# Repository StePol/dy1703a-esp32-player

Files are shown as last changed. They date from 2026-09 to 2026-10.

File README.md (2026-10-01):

# DY1703A ESP32 Audio Player

Prehrávač zvukov založený na module **DY1703A / DY-SV17F** a riadený **ESP32 DevKit**. Projekt obsahuje firmvér, KiCad schému a lokálne KiCad knižnice.

> Dokumentácia zodpovedá aktuálnemu obsahu vetvy `main`.

## Funkcie

- prehrávanie až 8 skladieb,
- 8 fyzických tlačidiel,
- webové ovládanie cez Wi-Fi,
- STA alebo vlastný AP režim,
- Play / Pauza / Stop,
- hlasitosť 0–30 a uloženie štartovacej hlasitosti,
- názvy skladieb,
- pevné identifikátory skladieb 1–8,
- samostatný externý odkaz pre každú skladbu,
- samostatné PNG/JPG logo pre každú skladbu,
- individuálne vibrácie,
- individuálny LOOP,
- orientačné meranie batérie,
- hlavné logo PNG/JPG v LittleFS a externý odkaz z hlavného loga,
- prehľad využitia LittleFS vrátane priestoru obsadeného logami,
- heslom chránené nastavenia,
- záloha/obnova konfigurácie,
- výrobné nastavenia,
- automatická verzia + Git SHA + build number,
- pomocný `release.py` na automatické zvýšenie PATCH/MINOR/MAJOR verzie,
- light sleep,
- servisné Serial príkazy.

## Dôležitá poznámka k Bluetooth

V `platformio.ini` je deklarovaná závislosť NimBLE-Arduino, ale aktuálny `src/main.cpp` BLE rozhranie nepoužíva. Starší README uvádzal Bluetooth ako vlastnosť projektu; podľa aktuálneho zdrojového kódu ho preto nemožno považovať za hotovú funkciu.

## Webové rozhranie

Nastavenia sú rozdelené na:

1. **Logo**
2. **Zariadenie a Wi-Fi**
3. **Nastavenie skladieb**
4. **Údržba**

Predvolené heslo pre nastavenia je `12345`. Predvolené AP heslo je `password`. Web používa HTTP bez TLS, preto je pri nasadení vhodné predvolené heslá zmeniť.

## UART DY1703A

| Funkcia | ESP32 |
|---|---:|
| TX → DY RX | GPIO17 |
| RX ← DY TX | GPIO16 |
| Baudrate | 9600 |
| Formát | 8N1 |

Firmware používa rámce začínajúce `0xAA` a podporuje play, pause, stop, previous, next, play track, volume a play state.

## GPIO podľa aktuálneho firmvéru

| Funkcia | GPIO |
|---|---:|
| Motor | 4 |
| Track 1 | 25 |
| Track 2 | 33 |
| Track 3 | 32 |
| Track 4 | 35 |
| Track 5 | 13 |
| Track 6 | 14 |
| Track 7 | 27 |
| Track 8 | 26 |
| Battery ADC | 34 |
| Battery enable | 23 |
| UART RX | 16 |
| UART TX | 17 |

> `docs/wiring.md` obsahuje staršie poradie GPIO pre tlačidlá. Pred výrobou treba zosúladiť firmware, schému a skutočnú kabeláž.

## Batéria

Používa sa spínaný odporový delič:

- ADC GPIO34,
- enable GPIO23,
- R_TOP 100 kΩ,
- R_BOTTOM 100 kΩ.

Delič je mimo merania odpojený. Percentá sú lineárny orientačný odhad 3,0–4,2 V.

## KiCad

Projekt je v `docs/kicad/dy1703a/` a obsahuje:

- `dy1703a.kicad_pro`
- `dy1703a.kicad_sch`
- `dy1703a.kicad_pcb`
- `dy1703a.kicad_sym`
- `dy1703a.pretty/`
- `LX-LCBST/`
- `fp-lib-table`
- `sym-lib-table`

Schéma má titulný blok s názvom **Zapojenie Prehravaca s ESP32 A DY1703A**, dátumom 2026-09-16, revíziou 1.0 a autorom Stefan Polacik.

**PCB je zatiaľ prázdna základná PCB štruktúra; nejde ešte o výrobný návrh.**

## Štruktúra

```text
dy1703a-esp32-player/
├── include/
│   └── config.h
├── lib/
│   ├── DY1703A/
│   └── BatteryMonitor/
├── src/
│   └── main.cpp
├── docs/
│   ├── architecture.md
│   ├── hardware.md
│   ├── software.md
│   ├── kicad.md
│   ├── wiring.md
│   └── kicad/dy1703a/
├── extra_script.py
├── release.py
├── platformio.ini
└── README.md
```

## Build

V koreňovom adresári:

```bash
pio run
pio run -t upload
pio device monitor
```

Monitor používa 115200 baud, upload 921600 baud.

## Vydanie novej verzie

Aktuálne číslo verzie netreba zisťovať ani zadávať ručne. Po commitnutí zmien a pri čistom pracovnom strome použite:

```bash
python release.py
```

Bez parametra sa automaticky zvýši PATCH. Pre novú funkčnú alebo hlavnú verziu:

```bash
python release.py minor
python release.py major
```

Skript načíta Git tagy, nájde najvyššiu verziu `vMAJOR.MINOR.PATCH`, vypočíta ďalšiu verziu, vypíše ju na kontrolu a až po potvrdení vytvorí anotovaný tag a odošle ho na `origin`.

## Dokumentácia

- [Architektúra firmvéru](docs/architecture.md)
- [Hardvér a zapojenie](docs/hardware.md)
- [Webové rozhranie a konfigurácia](docs/software.md)
- [KiCad projekt](docs/kicad.md)
- [Pôvodný dokument zapojenia](docs/wiring.md)

## Stav projektu

Firmvér pokrýva základnú funkčnosť prehrávača, Wi-Fi/webové ovládanie, konfiguráciu, logo, batériu, vibrácie, LOOP, light sleep a servisné Serial príkazy.

Hardvérová časť má aktuálnu KiCad schému a projektové lokálne knižnice. PCB návrh ešte nie je vytvorený.

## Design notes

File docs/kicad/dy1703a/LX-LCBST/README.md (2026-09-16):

# LX-LCBST KiCad knižnica

Obsahuje symbol, footprint a jednoduchý 3D model pre modul
"TP4056 USB-C Li-ion nabíjačka + DC-DC boost" (LX-LCBST).

⚠️ POZOR: fyzické rozmery (doska ~20×17 mm, rozostup pätiek 4 mm,
výška konektora ~3,6 mm) sú ODHADNUTÉ z pravítka na fotke, nie
z presného merania. Pred výrobou plošného spoja si modul premeraj
posuvným meradlom a footprint podľa potreby uprav v KiCad
Footprint Editore.

## Obsah
- `LX-LCBST.kicad_sym` – schematická značka (6 pinov: IN+, IN-, B+, B-, VO+, VO-)
- `LX-LCBST.pretty/LX-LCBST_Module.kicad_mod` – footprint (8 pätiek, priechodzie)
- `LX-LCBST.pretty/LX-LCBST_Module.wrl` – 3D model (doska + blok konektora)

## Inštalácia (KiCad 7/8)

1. Rozbaľ ZIP niekam natrvalo, napr. `Dokumenty/KiCad/knižnice/LX-LCBST_KiCad_Library`.
2. V KiCad otvor **Preferences → Manage Symbol Libraries…**
   - záložka *Global* alebo *Project* → **Add existing library**
   - vyber súbor `LX-LCBST.kicad_sym`, nickname napr. `LX-LCBST`
3. V KiCad otvor **Preferences → Manage Footprint Libraries…**
   - **Add existing library** → vyber priečinok `LX-LCBST.pretty`
   - nickname napr. `LX-LCBST`
4. V schéme potom nájdeš symbol pod menom knižnice `LX-LCBST` →
   `LX-LCBST_Boost_Charger`, footprint sa napojí automaticky
   (pole Footprint je predvyplnené).

## 3D model
Cesta k modelu je v footprinte nastavená ako
`${KIPRJMOD}/LX-LCBST.pretty/LX-LCBST_Module.wrl`, čo funguje len ak
je knižnica priamo v priečinku KiCad projektu. Ak knižnicu držíš
inde, over/priprav si cestu v **Footprint Properties → 3D Models**:
buď oprav cestu ručne, alebo si over relatívnu cestu, alebo
klikni "Add 3D Shape" a vyber `LX-LCBST_Module.wrl` v priečinku
`LX-LCBST.pretty` – scale nechaj na 0.393701 / 0.393701 / 0.393701.

## Piny
| Pin | Popis |
|-----|---|
| IN+ | vstup nabíjania (USB-C, +) |
| IN- | vstup nabíjania (GND) |
| B+  | Li-ion článok (+) |
| B-  | Li-ion článok (-) |
| VO+ | boost výstup (+), 2× vyvedené |
| VO- | boost výstup (-), 2× vyvedené |

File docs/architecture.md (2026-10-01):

# Architektúra firmvéru

## Prehľad

Firmvér je sústredený v `src/main.cpp`. Hardvérové konštanty sú v `include/config.h`. Ovládač DY1703A a batériový monitor sú oddelené do vlastných PlatformIO knižníc.

```text
                 +----------------------+
                 |        ESP32         |
                 |                      |
 tlačidlá 1..8 ->| GPIO                 |
 Wi-Fi <-------->| Web server           |
 USB Serial <--->| servisné príkazy     |
 GPIO17 TX ------> DY1703A              |
 GPIO16 RX <------ DY1703A              |
 GPIO4 ----------> motor driver         |
 GPIO34 <--------- battery ADC           |
 GPIO23 ----------> battery switch      |
                 +----------------------+
```

## Hlavné moduly

### `src/main.cpp`
Zodpovedá za inicializáciu, Preferences, Wi-Fi, web server, autentifikáciu nastavení, LittleFS/logo, tlačidlá, prehrávanie, hlasitosť, LOOP, vibrácie, batériu, light sleep a Serial servis.

### `include/config.h`
Obsahuje pinout a systémové konštanty pre UART, tlačidlá, Wi-Fi, batériu, motor a časové limity.

### `lib/DY1703A/`
Implementuje UART príkazy play, pause, stop, previous, next, play track, volume a play state.

### `lib/BatteryMonitor/`
Implementuje spínané meranie batérie cez ADC. Delič je počas nečinnosti odpojený.

### `extra_script.py`
PlatformIO pre-build skript generujúci informácie o builde z Git-u.

### `release.py`
Pomocný skript pre vydanie novej semantickej verzie. Automaticky nájde najvyšší tag `vMAJOR.MINOR.PATCH`, zvýši PATCH/MINOR/MAJOR, po potvrdení vytvorí anotovaný tag a odošle ho na `origin`.

## Stav prehrávania

Firmware používa `currentTrack`, `currentPlaying` a `loopPlaybackArmed`. Približne každých 300 ms číta stav DY1703A. Pri prechode PLAY → STOP a zapnutom LOOP znovu spustí aktuálnu skladbu.

## Konfigurácia

Preferences namespace:

`settings`

Používané kľúče zahŕňajú `device`, `apssid`, `appass`, `ssid`, `wpass`, `setpass`, `volume`, `logourl`, `trk1..trk8`, `url1..url8`, `vib1..vib8`, `lop1..lop8`.

## Web API

Verejné:
```text
GET /
GET /logo
GET /track-logo?track=N
GET /api/status
GET /api/play
GET /api/pause
GET /api/stop
GET /api/volume?value=N
GET /api/volume/set?value=N
GET /settings-login
POST /api/login
```

Chránené:
```text
GET  /settings
GET  /api/settings
POST /api/settings
DELETE /api/logo
POST /api/logo
DELETE /api/track-logo?track=N
POST /api/track-logo?track=N
POST /api/defaults
GET  /api/backup
POST /api/restore
```

## Autentifikácia

Po úspešnom prihlásení sa vytvorí session token a cookie `DYSESSION=<token>`. Token sa po reštarte ESP32 stratí.

## LittleFS

Používané súbory:
- hlavné logo: `/logo`,
- logá skladieb: `/track1.logo` až `/track8.logo`.

Dočasné uploady používajú `/logo.tmp` a `/track.tmp`. Maximálna veľkosť každého loga je 300 kB. Stránka Údržba zobrazuje celkové/použité/voľné miesto LittleFS a súčet veľkosti všetkých log.

## Serial API

```text
CMD:WIFI_SSID=<ssid>
CMD:WIFI_PASSWORD=<heslo>
CMD:GET_WIFI
CMD:RESTART
```

Pri `CMD:GET_WIFI` sa heslo nevypisuje.

## Hlavná slučka

```text
pollSerialCommands()
        |
handleButtons()
        |
player.poll()
        |
play state / LOOP / motor
        |
batéria
        |
pending restart
        |
Wi-Fi
        |
light sleep
```

## Časovanie

| Funkcia | Hodnota |
|---|---:|
| Stav DY1703A + motor | 300 ms |
| Batéria | 10 s |
| AP grace po odpojení | 60 s |
| STA timeout | 15 s |
| Light sleep po nečinnosti | 30 s |
| Kontrola light sleep | 5 s |
| Debounce tlačidiel | 40 ms |

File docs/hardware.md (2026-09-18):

# Hardvér a zapojenie

## Základné časti

Aktuálny KiCad projekt obsahuje ESP32 DevKit, DY1703A, Li-ion/LiPo článok, LX-LCBST nabíjací/boost modul, reproduktor, 8 tlačidiel, vibračný motor, tranzistorové riadenie, batériový merací obvod, LED a pasívne súčiastky.

Zdrojom pravdy pre GPIO a systémové hardvérové nastavenia firmvéru je `include/config.h`.

## ESP32 ↔ DY1703A

| ESP32 | GPIO | DY1703A |
|---|---:|---|
| TX | GPIO17 | RX |
| RX | GPIO16 | TX |
| GND | GND | GND |

UART: **9600, 8N1**.

## Tlačidlá

Všetkých 8 tlačidiel je aktívnych LOW.

| Skladba | GPIO | Poznámka |
|---:|---:|---|
| 1 | 25 | aktívne LOW |
| 2 | 33 | aktívne LOW |
| 3 | 32 | aktívne LOW |
| 4 | 35 | aktívne LOW, input-only |
| 5 | 13 | aktívne LOW |
| 6 | 14 | aktívne LOW |
| 7 | 27 | aktívne LOW |
| 8 | 26 | aktívne LOW |

GPIO35 je vstup-only a nemá interný pull-up, preto tlačidlo na GPIO35 vyžaduje externý pull-up na 3.3 V.

## Batéria

| Signál | Hodnota |
|---|---:|
| ADC | GPIO34 |
| ENABLE | GPIO23 |
| R_TOP | 100 kΩ |
| R_BOTTOM | 100 kΩ |

Delič sa pripája iba počas merania. Firmware používa 12-bit ADC a 11 dB attenuáciu.

## Vibračný motor

- GPIO4
- aktívna úroveň HIGH
- motor je riadený cez externý tranzistorový stupeň.

## Napájanie

Zámer podľa aktuálnej dokumentácie:

```text
Li-ion/LiPo
     |
     v
LX-LCBST / nabíjanie + boost
     |
     +----> 5 V -> ESP32
     |
     +----> 5 V -> DY1703A
```

Všetky časti musia mať spoločnú GND.

## Kompletný prehľad GPIO

| GPIO | Funkcia |
|---:|---|
| 4 | vibračný motor |
| 13 | tlačidlo 5 |
| 14 | tlačidlo 6 |
| 16 | UART RX |
| 17 | UART TX |
| 23 | BAT_EN |
| 25 | tlačidlo 1 |
| 26 | tlačidlo 8 |
| 27 | tlačidlo 7 |
| 32 | tlačidlo 3 |
| 33 | tlačidlo 2 |
| 34 | BAT_IN / ADC |
| 35 | tlačidlo 4, input-only |

## KiCad schéma

`docs/kicad/dy1703a/dy1703a.kicad_sch`

Titulný blok:
- názov: **Zapojenie Prehravaca s ESP32 A DY1703A**
- dátum: **2026-09-16**
- revízia: **1.0**
- autor: **Stefan Polacik**
- GitHub: **StePol/dy1703a-esp32-player**

## PCB

`dy1703a.kicad_pcb` je v aktuálnom repozitári iba základná prázdna PCB štruktúra bez rozmiestnených footprintov. Výrobná PCB dokumentácia teda ešte nie je hotová.

## Lokálne knižnice

Projekt obsahuje vlastný symbol/footprint DY1703A a lokálnu knižnicu LX-LCBST vrátane 3D modelu.

Footprint LX-LCBST uvádza rozmery ako odhad podľa fotografie; pred výrobou ich treba overiť.

## Dôležité upozornenie pred výrobou

Pred výrobou alebo osadením hardvéru treba overiť, že KiCad schéma a skutočné zapojenie zodpovedajú GPIO mapovaniu v `include/config.h`, najmä mapovaniu ôsmich tlačidiel.

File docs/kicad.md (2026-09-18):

# KiCad projekt

## Umiestnenie

`docs/kicad/dy1703a/`

## Súbory

```text
dy1703a.kicad_pro
dy1703a.kicad_sch
dy1703a.kicad_pcb
dy1703a.kicad_sym
dy1703a.pretty/
fp-lib-table
sym-lib-table
LX-LCBST/
```

## Schéma

`dy1703a.kicad_sch` obsahuje lokálne symboly pre DY1703A, ESP32 DevKit, LX-LCBST, batériu, reproduktor, motor, tlačidlá, LED, diódy, tranzistory a pasívne súčiastky.

Titulný blok:
| Položka | Hodnota |
|---|---|
| Názov | Zapojenie Prehravaca s ESP32 A DY1703A |
| Dátum | 2026-09-16 |
| Revízia | 1.0 |
| Autor | Stefan Polacik |
| Firma | TRIX Lubomir Drgan |
| GitHub | StePol/dy1703a-esp32-player |

## Lokálne symboly

`dy1703a.kicad_sym` obsahuje okrem iných DY1703A, ESP32_DevKit_V1_DOIT_30GPIOs, LX-LCBST_Boost_Charger, Membrane_Keypad_1x4, Motor_DC, Speaker, Battery_Cell, BSS84, BS170, BC546, BC557, STPS1150, 1N4148 a napájacie symboly.

## DY1703A footprint

`dy1703a.pretty/DY1703A.kicad_mod` obsahuje 18 vývodov, pin-1 marker, obrys a označenie DY1703A.

## LX-LCBST

Adresár `LX-LCBST/` obsahuje symbol, footprint a 3D model. Symbol definuje IN+, IN-, B+, B-, VO+, VO-. Footprint obsahuje kontakty na oboch stranách modulu.

## Knižničné tabuľky

`fp-lib-table` používa projektové cesty:
```text
${KIPRJMOD}/dy1703a.pretty
${KIPRJMOD}/LX-LCBST/LX-LCBST.pretty
```

`sym-lib-table` používa:
```text
${KIPRJMOD}/dy1703a.kicad_sym
${KIPRJMOD}/LX-LCBST/LX-LCBST.kicad_sym
```

## PCB

`dy1703a.kicad_pcb` je zatiaľ prázdna základná PCB štruktúra. Nie je to hotová doska pripravená na výrobu.

## Prenos projektu

Treba zachovať celú štruktúru `docs/kicad/dy1703a/`, vrátane lokálnych knižníc a oboch tabuliek knižníc.

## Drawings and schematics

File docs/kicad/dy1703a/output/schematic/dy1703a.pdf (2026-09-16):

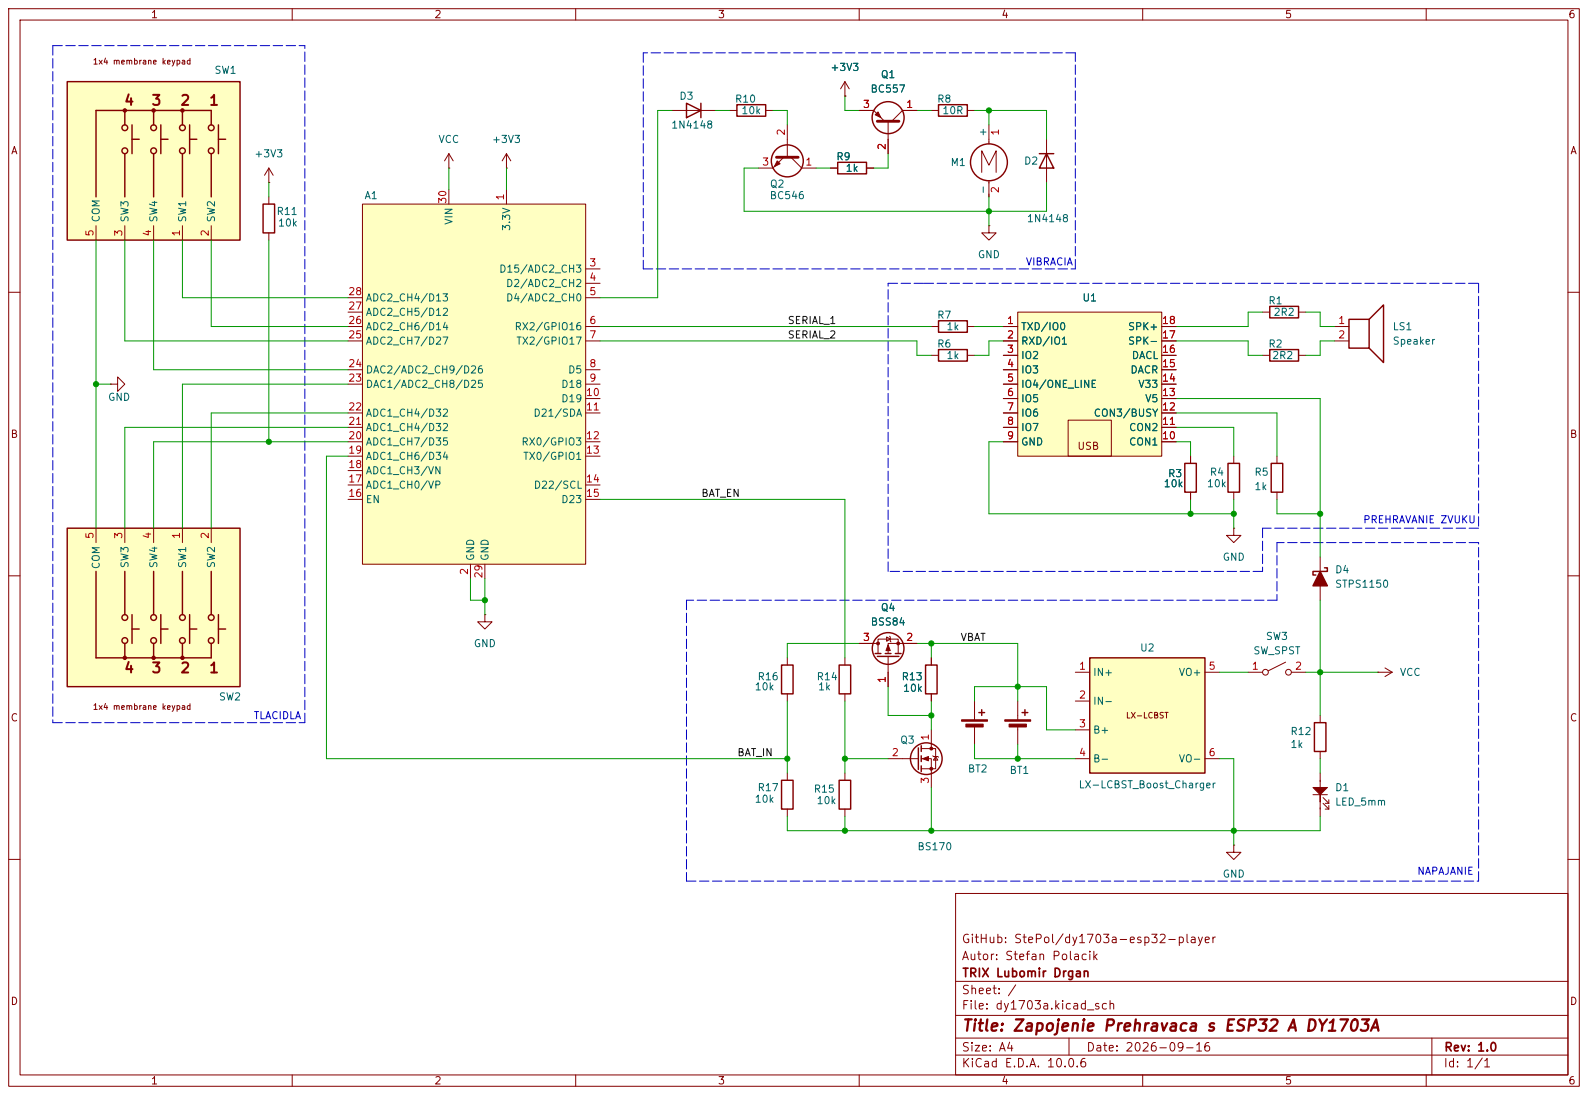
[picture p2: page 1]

TX0/GPIO1 13 D22/SCL 14 D23 15 EN 16 ADC1_CH0/VP 17 ADC1_CH3/VN 18 ADC1_CH6/D34 19 ADC1_CH7/D35 20 ADC1_CH4/D32 21 ADC1_CH4/D32 22 DAC1/ADC2_CH8/D25 23 DAC2/ADC2_CH9/D26 24

Size: A4 | Rev: 1.0
KiCad E.D.A. 10.0.6 | Id: 1/1

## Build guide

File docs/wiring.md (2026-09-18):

# Schéma zapojenia

Tento dokument zodpovedá aktuálnemu firmvéru. **Zdrojom pravdy pre GPIO a systémové hardvérové nastavenia je `include/config.h`.**

## 1. Napájanie

```text
Li-ion/LiPo batéria
        │
        ▼
   nabíjací modul
        │
        ▼
   Boost 5 V
     ├──► ESP32 – VIN/5V
     └──► DY1703A – VCC

GND všetkých častí musí byť spoločná.
```

- DY1703A je napájaný z 5 V.
- ESP32 je napájaný na VIN/5V.
- Logická časť ESP32 pracuje s 3.3 V.
- Reproduktor sa pripája na `SPK+` a `SPK-` modulu DY1703A.

## 2. ESP32 ↔ DY1703A – UART

Firmware používa HardwareSerial UART2:

| ESP32 | GPIO | DY1703A | Poznámka |
|---|---:|---|---|
| TX2 | **GPIO17** | **RXD / IO1** | ESP32 → DY1703A |
| RX2 | **GPIO16** | **TXD / IO0** | DY1703A → ESP32 |
| GND | GND | GND | spoločná zem |
| 5V | VIN/5V | VCC | napájanie modulu |

Parametre UART:

- baudrate: **9600**
- formát: **8N1**
- UART: **UART2**

## 3. Osem tlačidiel

Každé tlačidlo je samostatne medzi príslušným GPIO a GND. Všetky tlačidlá sú aktívne LOW.

Aktuálne mapovanie podľa `include/config.h`:

| Tlačidlo | Skladba | ESP32 GPIO |
|---:|---:|---:|
| KEY1 | 1 | **GPIO25** |
| KEY2 | 2 | **GPIO33** |
| KEY3 | 3 | **GPIO32** |
| KEY4 | 4 | **GPIO35** |
| KEY5 | 5 | **GPIO13** |
| KEY6 | 6 | **GPIO14** |
| KEY7 | 7 | **GPIO27** |
| KEY8 | 8 | **GPIO26** |

### GPIO35

GPIO35 je vstup-only pin ESP32 a nemá interný pull-up. Pre tlačidlo KEY4 je preto potrebný **externý pull-up na 3.3 V**.

Ostatné tlačidlá používajú príslušné GPIO podľa firmvérovej konfigurácie.

## 4. Vibračný motorček

Firmware používa:

```text
MOTOR_PIN = GPIO4
MOTOR_ACTIVE_LEVEL = HIGH
```

GPIO4 ovláda externý tranzistorový stupeň. Motor sa teda nepripája priamo na GPIO ESP32.

Motor je aktívny počas prehrávania skladby, ak je pre danú skladbu zapnutá vibrácia.

## 5. Meranie batérie

| Funkcia | ESP32 |
|---|---:|
| BAT_IN / ADC | **GPIO34** |
| BAT_EN | **GPIO23** |
| R_TOP | **100 kΩ** |
| R_BOTTOM | **100 kΩ** |

Batériové napätie sa meria cez spínaný odporový delič. GPIO23 slúži na jeho povolenie iba počas merania, aby sa znížil odber batérie.

Firmware používa 12-bit ADC a 11 dB attenuáciu.

## 6. Prehľad GPIO

| GPIO | Funkcia |
|---:|---|
| 4 | vibračný motor |
| 13 | tlačidlo 5 |
| 14 | tlačidlo 6 |
| 16 | UART RX |
| 17 | UART TX |
| 23 | BAT_EN |
| 25 | tlačidlo 1 |
| 26 | tlačidlo 8 |
| 27 | tlačidlo 7 |
| 32 | tlačidlo 3 |
| 33 | tlačidlo 2 |
| 34 | BAT_IN / ADC |
| 35 | tlačidlo 4, input-only |

## 7. Dôležité upozornenie pred výrobou

Tento dokument popisuje **aktuálne GPIO mapovanie podľa `include/config.h`**. Pri zapájaní hardvéru treba použiť práve toto mapovanie.

Najmä poradie tlačidiel je:

```text
Skladba 1 → GPIO25
Skladba 2 → GPIO33
Skladba 3 → GPIO32
Skladba 4 → GPIO35
Skladba 5 → GPIO13
Skladba 6 → GPIO14
Skladba 7 → GPIO27
Skladba 8 → GPIO26
```

Pred výrobou finálnej dosky je potrebné overiť, že KiCad schéma a skutočné zapojenie zodpovedajú tomuto mapovaniu.

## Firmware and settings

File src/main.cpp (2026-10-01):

#include <Arduino.h>
#include <WiFi.h>
#include <DNSServer.h>
#include <Preferences.h>
#include <LittleFS.h>
#include "build_info.h"
#include <AsyncTCP.h>
#include <ESPAsyncWebServer.h>
#include <esp_sleep.h>
#include <driver/gpio.h>
#include "config.h"
#include "DY1703A.h"
#include "BatteryMonitor.h"

HardwareSerial DYSerial(DY_UART_NUM);
DY1703A player(DYSerial);
BatteryMonitor battery(BATTERY_ADC_PIN, BATTERY_R_TOP, BATTERY_R_BOTTOM, BATTERY_ENABLE_PIN);
AsyncWebServer server(WEB_SERVER_PORT);
DNSServer dnsServer;
Preferences preferences;

struct TrackButton { uint8_t pin; uint8_t trackNumber; bool lastState; unsigned long lastChangeMs; };
TrackButton buttons[8];

uint8_t currentVolume = 20;
uint8_t currentTrack = 0;
bool currentPlaying = false;
bool loopPlaybackArmed = false;
uint32_t batteryMv = 0;
uint8_t batteryPct = 0;
unsigned long lastActivityMs = 0;

bool wifiActive = false;
bool webServerStarted = false;
bool wifiIsSta = false;
unsigned long wifiConnectDeadlineMs = 0;
unsigned long wifiDisconnectGraceDeadlineMs = 0;
bool wifiRestartPending = false;
unsigned long wifiRestartAtMs = 0;

String deviceName;
String apSsid;
String apPassword;
String staSsid;
String staPassword;
String settingsPassword;
String logoUrl;
bool logoExists = false;
String trackNames[8];
String trackLinks[8];
bool trackLogoExists[8];
bool vibrationEnabled[8];
bool loopEnabled[8];

String settingsSessionToken;
String restoreBuffer;
bool restoreUploadOk = false;

const char *DEFAULT_DEVICE = "DY1703A Player";
// Version and Git commit are generated automatically by PlatformIO extra_script.py.
const char *DEFAULT_AP_SSID = WIFI_AP_SSID;
const char *DEFAULT_AP_PASSWORD = WIFI_AP_PASS;
const char *DEFAULT_SETTINGS_PASSWORD = "12345";
const char *LOGO_PATH = "/logo";
const size_t MAX_LOGO_SIZE = 300 * 1024;
const size_t MAX_TRACK_LOGO_SIZE = 300 * 1024;

String trackLogoPath(uint8_t track) {
    return "/track" + String(track) + ".logo";
}

bool isInputOnlyPin(uint8_t pin) {
    for (uint8_t p : INPUT_ONLY_PINS) if (p == pin) return true;
    return false;
}

String serialCommandBuffer;

void processSerialCommand(String line) {
    line.trim();
    if (line.length() == 0) return;

    if (line.startsWith("CMD:WIFI_SSID=")) {
        String value = line.substring(14);
        value.trim();
        if (value.length() > 32) value = value.substring(0, 32);
        preferences.putString("ssid", value);
        staSsid = value;
        Serial.println("OK WIFI_SSID");
        return;
    }

    if (line.startsWith("CMD:WIFI_PASSWORD=")) {
        String value = line.substring(18);
        value.trim();
        if (value.length() < 8 || value.length() > 63) {
            Serial.println("ERROR WIFI_PASSWORD length");
            return;
        }
        preferences.putString("wpass", value);
        staPassword = value;
        Serial.println("OK WIFI_PASSWORD");
        return;
    }

    if (line == "CMD:RESTART") {
        Serial.println("OK RESTART");
        delay(100);
        ESP.restart();
        return;
    }

    if (line == "CMD:GET_WIFI") {
        Serial.printf("WIFI_SSID=%s\n", staSsid.c_str());
        Serial.println("WIFI_PASSWORD=<hidden>");
        return;
    }

    Serial.println("ERROR UNKNOWN_COMMAND");
}

void pollSerialCommands() {
    while (Serial.available()) {
        char ch = (char)Serial.read();
        if (ch == '\n' || ch == '\r') {
            if (serialCommandBuffer.length()) {
                processSerialCommand(serialCommandBuffer);
                serialCommandBuffer = "";
            }
        } else if (serialCommandBuffer.length() < 160) {
            serialCommandBuffer += ch;
        } else {
            serialCommandBuffer = "";
            Serial.println("ERROR COMMAND_TOO_LONG");
        }
    }
}

void setMotor(bool on) {
    digitalWrite(MOTOR_PIN, on ? MOTOR_ACTIVE_LEVEL :
                 (MOTOR_ACTIVE_LEVEL == HIGH ? LOW : HIGH));
}

void setupButtons() {
    for (uint8_t i = 0; i < 8; i++) {
        buttons[i].pin = TRACK_BUTTON_PINS[i];
        buttons[i].trackNumber = i + 1;
        buttons[i].lastState = HIGH;
        buttons[i].lastChangeMs = 0;
        pinMode(buttons[i].pin, isInputOnlyPin(buttons[i].pin) ? INPUT : INPUT_PULLUP);
    }
    pinMode(MOTOR_PIN, OUTPUT);
    setMotor(false);
}

void loadSettings() {
    preferences.begin("settings", false);
    deviceName = preferences.getString("device", DEFAULT_DEVICE);
    apSsid = preferences.getString("apssid", DEFAULT_AP_SSID);
    apPassword = preferences.getString("appass", DEFAULT_AP_PASSWORD);
    staSsid = preferences.getString("ssid", WIFI_STA_SSID);
    staPassword = preferences.getString("wpass", WIFI_STA_PASS);
    settingsPassword = preferences.getString("setpass", DEFAULT_SETTINGS_PASSWORD);
    currentVolume = (uint8_t)constrain(preferences.getUChar("volume", 20), 0, 30);
    logoUrl = preferences.getString("logourl", "");
    logoExists = LittleFS.exists(LOGO_PATH);

    if (deviceName.length() == 0) deviceName = DEFAULT_DEVICE;
    if (apSsid.length() == 0) apSsid = DEFAULT_AP_SSID;
    if (apPassword.length() < 8 || apPassword.length() > 63) apPassword = DEFAULT_AP_PASSWORD;
    if (settingsPassword.length() == 0) settingsPassword = DEFAULT_SETTINGS_PASSWORD;

    for (uint8_t i = 0; i < 8; i++) {
        char key[8];
        snprintf(key, sizeof(key), "trk%u", i + 1);
        String defaultName = "Skladba " + String(i + 1);
        trackNames[i] = preferences.getString(key, defaultName.c_str());
        if (trackNames[i].length() == 0) trackNames[i] = defaultName;
        if (trackNames[i].length() > 40) trackNames[i] = trackNames[i].substring(0, 40);

        char vkey[8];
        snprintf(vkey, sizeof(vkey), "vib%u", i + 1);
        vibrationEnabled[i] = preferences.getBool(vkey, false);
        char lkey[8]; snprintf(lkey, sizeof(lkey), "lop%u", i + 1);
        loopEnabled[i] = preferences.getBool(lkey, false);
        char ukey[8]; snprintf(ukey, sizeof(ukey), "url%u", i + 1);
        trackLinks[i] = preferences.getString(ukey, "");
        if (trackLinks[i].length() > 200) trackLinks[i] = trackLinks[i].substring(0, 200);
        trackLogoExists[i] = LittleFS.exists(trackLogoPath(i + 1));
    }

    Serial.printf("Nastavenia: zariadenie='%s', AP SSID='%s', STA SSID='%s', hlasitost=%u\n",
                  deviceName.c_str(), apSsid.c_str(), staSsid.c_str(), currentVolume);
}

void saveSettings(const String &newDeviceName, const String &newApSsid,
                  const String &newApPassword, const String &newStaSsid,
                  const String &newStaPassword, const String &newSettingsPassword,
                  uint8_t newVolume, const String newTrackNames[8],
                  const bool newVibrationEnabled[8],
                  const bool newLoopEnabled[8]) {
    deviceName = newDeviceName.length() ? newDeviceName : DEFAULT_DEVICE;
    apSsid = newApSsid.length() ? newApSsid : DEFAULT_AP_SSID;
    apPassword = newApPassword;
    staSsid = newStaSsid;
    staPassword = newStaPassword;
    settingsPassword = newSettingsPassword.length() ? newSettingsPassword : DEFAULT_SETTINGS_PASSWORD;
    currentVolume = constrain(newVolume, 0, 30);

    if (deviceName.length() > 32) deviceName = deviceName.substring(0, 32);
    if (apSsid.length() > 32) apSsid = apSsid.substring(0, 32);
    if (apPassword.length() < 8 || apPassword.length() > 63) apPassword = DEFAULT_AP_PASSWORD;
    if (settingsPassword.length() > 32) settingsPassword = settingsPassword.substring(0, 32);

    preferences.putString("device", deviceName);
    preferences.putString("apssid", apSsid);
    preferences.putString("appass", apPassword);
    preferences.putString("ssid", staSsid);
    preferences.putString("wpass", staPassword);
    preferences.putString("setpass", settingsPassword);
    preferences.putUChar("volume", currentVolume);
    preferences.putString("logourl", logoUrl);

    for (uint8_t i = 0; i < 8; i++) {
        String name = newTrackNames[i];
        name.trim();
        if (name.length() == 0) name = "Skladba " + String(i + 1);
        if (name.length() > 40) name = name.substring(0, 40);
        trackNames[i] = name;
        vibrationEnabled[i] = newVibrationEnabled[i];
        loopEnabled[i] = newLoopEnabled[i];

        char key[8]; snprintf(key, sizeof(key), "trk%u", i + 1);
        preferences.putString(key, trackNames[i]);
        char vkey[8]; snprintf(vkey, sizeof(vkey), "vib%u", i + 1);
        preferences.putBool(vkey, vibrationEnabled[i]);
        char lkey[8]; snprintf(lkey, sizeof(lkey), "lop%u", i + 1);
        preferences.putBool(lkey, loopEnabled[i]);
    }
}

void resetToDefaults() {
    String defaults[8];
    bool noVibration[8];
    bool noLoop[8];
    for (uint8_t i = 0; i < 8; i++) {
        defaults[i] = "Skladba " + String(i + 1);
        noVibration[i] = false;
        noLoop[i] = false;
        trackLinks[i] = "";
        preferences.remove(("url" + String(i + 1)).c_str());
        String lp = trackLogoPath(i + 1);
        if (LittleFS.exists(lp)) LittleFS.remove(lp);
        trackLogoExists[i] = false;
    }
    saveSettings(DEFAULT_DEVICE, DEFAULT_AP_SSID, DEFAULT_AP_PASSWORD,
                 "", "", DEFAULT_SETTINGS_PASSWORD, 20, defaults, noVibration, noLoop);
    player.setVolume(currentVolume);
}

String htmlEscape(const String &value) {
    String s = value;
    s.replace("&", "&amp;"); s.replace("<", "&lt;"); s.replace(">", "&gt;");
    s.replace("\"", "&quot;"); s.replace("'", "&#39;");
    return s;
}

String jsonEscape(const String &value) {
    String s = value;
    s.replace("\\", "\\\\"); s.replace("\"", "\\\"");
    s.replace("\r", "\\r"); s.replace("\n", "\\n");
    return s;
}

bool settingsAuthorized(AsyncWebServerRequest *request) {
    if (!request->hasHeader("Cookie")) return false;
    String cookie = request->getHeader("Cookie")->value();
    return settingsSessionToken.length() > 0 &&
           cookie.indexOf("DYSESSION=" + settingsSessionToken) >= 0;
}

void redirectToLogin(AsyncWebServerRequest *request) {
    request->redirect("/settings-login");
}

String makeBackup() {
    String out;
    out.reserve(5000);
    out += "# DY1703A Player configuration\n";
    out += "version=1\n";
    out += "device=" + deviceName + "\n";
    out += "apssid=" + apSsid + "\n";
    out += "appass=" + apPassword + "\n";
    out += "ssid=" + staSsid + "\n";
    out += "wpass=" + staPassword + "\n";
    out += "setpass=" + settingsPassword + "\n";
    out += "volume=" + String(currentVolume) + "\n";
    for (uint8_t i = 0; i < 8; i++) {
        out += "trk" + String(i + 1) + "=" + trackNames[i] + "\n";
        out += "vib" + String(i + 1) + "=" + String(vibrationEnabled[i] ? 1 : 0) + "\n";
        out += "lop" + String(i + 1) + "=" + String(loopEnabled[i] ? 1 : 0) + "\n";
        out += "url" + String(i + 1) + "=" + trackLinks[i] + "\n";
    }
    return out;
}

bool parseBackup(const String &data) {
    String newDevice = DEFAULT_DEVICE, newApSsid = DEFAULT_AP_SSID;
    String newApPassword = DEFAULT_AP_PASSWORD, newStaSsid, newStaPassword;
    String newSettingsPassword = DEFAULT_SETTINGS_PASSWORD;
    String newTrackNames[8];
    bool newVibration[8];
    bool newLoop[8];
    String newTrackLinks[8];
    int newVolume = 20;

    for (uint8_t i = 0; i < 8; i++) {
        newTrackNames[i] = "Skladba " + String(i + 1);
        newVibration[i] = false;
        newLoop[i] = false;
        newTrackLinks[i] = "";
    }

    int start = 0;
    while (start < data.length()) {
        int end = data.indexOf('\n', start);
        if (end < 0) end = data.length();
        String line = data.substring(start, end);
        line.trim();
        start = end + 1;
        if (line.length() == 0 || line.startsWith("#")) continue;

        int eq = line.indexOf('=');
        if (eq <= 0) continue;
        String key = line.substring(0, eq);
        String value = line.substring(eq + 1);

        if (key == "device") newDevice = value;
        else if (key == "apssid") newApSsid = value;
        else if (key == "appass") newApPassword = value;
        else if (key == "ssid") newStaSsid = value;
        else if (key == "wpass") newStaPassword = value;
        else if (key == "setpass") newSettingsPassword = value;
        else if (key == "volume") newVolume = value.toInt();
        else if (key.startsWith("trk")) {
            int n = key.substring(3).toInt();
            if (n >= 1 && n <= 8) newTrackNames[n - 1] = value;
        } else if (key.startsWith("vib")) {
            int n = key.substring(3).toInt();
            if (n >= 1 && n <= 8) newVibration[n - 1] = value.toInt() != 0;
        } else if (key.startsWith("lop")) {
            int n = key.substring(3).toInt();
            if (n >= 1 && n <= 8) newLoop[n - 1] = value.toInt() != 0;
        } else if (key.startsWith("url")) {
            int n = key.substring(3).toInt();
            if (n >= 1 && n <= 8) newTrackLinks[n - 1] = value;
        }
    }

    newDevice.trim(); newApSsid.trim(); newApPassword.trim();
    newStaSsid.trim(); newSettingsPassword.trim();
    if (newDevice.length() == 0 || newApSsid.length() == 0) return false;
    if (newApPassword.length() < 8 || newApPassword.length() > 63) return false;
    if (newSettingsPassword.length() == 0) return false;

    newVolume = constrain(newVolume, 0, 30);
    saveSettings(newDevice, newApSsid, newApPassword, newStaSsid,
                 newStaPassword, newSettingsPassword, (uint8_t)newVolume,
                 newTrackNames, newVibration, newLoop);
    for (uint8_t i = 0; i < 8; i++) {
        newTrackLinks[i].trim();
        if (newTrackLinks[i].length() > 200) newTrackLinks[i] = newTrackLinks[i].substring(0, 200);
        if (newTrackLinks[i].length() && !(newTrackLinks[i].startsWith("http://") || newTrackLinks[i].startsWith("https://"))) newTrackLinks[i] = "";
        trackLinks[i] = newTrackLinks[i];
        preferences.putString(("url" + String(i + 1)).c_str(), trackLinks[i]);
    }
    player.setVolume(currentVolume);
    return true;
}

void setupWebServer();

void startAP() {
    Serial.printf("Spúšťam WiFi AP '%s'...\n", apSsid.c_str());
    WiFi.mode(WIFI_AP);
    WiFi.setSleep(false);

    bool ok = WiFi.softAP(apSsid.c_str(), apPassword.c_str());
    if (!ok) {
        Serial.println(F("CHYBA: WiFi AP sa nepodarilo spustiť"));
        WiFi.mode(WIFI_OFF);
        wifiActive = false;
        return;
    }

    wifiActive = true;
    wifiIsSta = false;
    wifiConnectDeadlineMs = millis() + WIFI_CONNECT_TIMEOUT_MS;
    wifiDisconnectGraceDeadlineMs = 0;

    dnsServer.start(53, "*", WiFi.softAPIP());
    setupWebServer();

    Serial.printf("WiFi AP: %s, IP: %s, heslo: %s\n",
                  apSsid.c_str(), WiFi.softAPIP().toString().c_str(), apPassword.c_str());
}

bool startSTA() {
    if (staSsid.length() == 0) return false;

    Serial.printf("Pripájam sa na WiFi '%s'...\n", staSsid.c_str());
    WiFi.mode(WIFI_STA);
    WiFi.setSleep(false);
    WiFi.begin(staSsid.c_str(), staPassword.c_str());

    unsigned long deadline = millis() + WIFI_STA_TIMEOUT_MS;
    while (WiFi.status() != WL_CONNECTED && (long)(millis() - deadline) < 0) {
        delay(100);
        Serial.print('.');
    }
    Serial.println();

    if (WiFi.status() != WL_CONNECTED) {
        Serial.println(F("WiFi STA: pripojenie zlyhalo -> prepínam na AP"));
        WiFi.disconnect(true, true);
        WiFi.mode(WIFI_OFF);
        return false;
    }

    wifiActive = true;
    wifiIsSta = true;
    wifiConnectDeadlineMs = 0;
    wifiDisconnectGraceDeadlineMs = 0;
    setupWebServer();

    Serial.printf("WiFi STA pripojená, IP: %s\n", WiFi.localIP().toString().c_str());
    return true;
}

void startWiFi() {
    if (wifiActive) return;
    if (staSsid.length() > 0 && startSTA()) return;
    startAP();
}

void stopWiFi() {
    if (!wifiActive) return;
    Serial.println(F("WiFi nečinné -> vypínam WiFi a povoľujem sleep"));

    if (!wifiIsSta) dnsServer.stop();
    if (wifiIsSta) WiFi.disconnect(true, true);
    else WiFi.softAPdisconnect(true);

    WiFi.mode(WIFI_OFF);
    wifiActive = false;
    wifiIsSta = false;
    wifiConnectDeadlineMs = 0;
    wifiDisconnectGraceDeadlineMs = 0;
}
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
void loop(){
    pollSerialCommands();
    static bool littleFsDiagLoopDone=false;
    if(!littleFsDiagLoopDone && millis()>5000){
        littleFsDiagLoopDone=true;
        Serial.println("[LittleFS] DIAGNOSTIKA PO 5 SEKUNDACH");
        Serial.printf("[LittleFS] total=%u used=%u free=%u exists_logo=%s\n",
                      (unsigned)LittleFS.totalBytes(), (unsigned)LittleFS.usedBytes(),
                      (unsigned)(LittleFS.totalBytes()-LittleFS.usedBytes()),
                      LittleFS.exists(LOGO_PATH) ? "ANO" : "NIE");
    }
    if(handleButtons())lastActivityMs=millis();
    player.poll();

    static unsigned long lastBatteryRead=0,lastMotorPoll=0;
    static bool wasPlaying=false;
    unsigned long now=millis();

    if(now-lastMotorPoll>=MOTOR_POLL_INTERVAL_MS){
        lastMotorPoll=now;
        uint8_t playState=player.playState();
        if(playState!=0xFF) currentPlaying=(playState==0x01);
        if(wasPlaying && !currentPlaying && loopPlaybackArmed && currentTrack>=1 && currentTrack<=8 && loopEnabled[currentTrack-1]){
            player.playTrack(currentTrack);
            currentPlaying=true;
            Serial.printf("[LOOP] koniec skladby -> opakujem skladbu %u\n", currentTrack);
        }
        wasPlaying=currentPlaying;
        setMotor(currentPlaying&&currentTrack>=1&&currentTrack<=8&&vibrationEnabled[currentTrack-1]);
        if(currentPlaying)lastActivityMs=now;
    }

    if(now-lastBatteryRead>=BATTERY_READ_INTERVAL_MS){
        lastBatteryRead=now;
        batteryMv=battery.readVoltageMv();
        batteryPct=battery.readPercent();
        String ip = wifiIsSta ? WiFi.localIP().toString() : (wifiActive ? WiFi.softAPIP().toString() : String("OFF"));
        Serial.printf("Batéria: %lu mV (~%u%%) | IP: %s\n", batteryMv, batteryPct, ip.c_str());
    }

    handlePendingWiFiRestart();
    handleWiFi();
    maybeEnterLightSleep();
}

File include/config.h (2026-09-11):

#pragma once

// --- UART k DY1703A ---
#define DY_UART_NUM     2
#define DY_TX_PIN       17
#define DY_RX_PIN       16
#define DY_BAUD_RATE    9600

// --- Tlačidlá pre priamu voľbu skladby (aktívne LOW) ---
// KEY1 -> skladba 1 -> GPIO25
// KEY2 -> skladba 2 -> GPIO33
// KEY3 -> skladba 3 -> GPIO32
// KEY4 -> skladba 4 -> GPIO35
// KEY5 -> skladba 5 -> GPIO13
// KEY6 -> skladba 6 -> GPIO14
// KEY7 -> skladba 7 -> GPIO27
// KEY8 -> skladba 8 -> GPIO26
constexpr uint8_t TRACK_BUTTON_PINS[8] = {25, 33, 32, 35, 13, 14, 27, 26};
constexpr uint8_t INPUT_ONLY_PIN_COUNT = 1;
constexpr uint8_t INPUT_ONLY_PINS[INPUT_ONLY_PIN_COUNT] = {35};
#define BTN_DEBOUNCE_MS 40

// --- WiFi / web rozhranie ---
#define WIFI_AP_SSID    "DY1703A-Player"
#define WIFI_AP_PASS    "password"
#define WEB_SERVER_PORT 80
#define WIFI_STA_SSID   ""
#define WIFI_STA_PASS   ""
#define WIFI_STA_TIMEOUT_MS 15000UL
#define WIFI_CONNECT_TIMEOUT_MS 90000UL
#define WIFI_DISCONNECT_GRACE_MS 60000UL

// --- BLE ---
#define BLE_DEVICE_NAME "DY1703A-Player"

// --- Batéria ---
#define BATTERY_ADC_PIN     34
#define BATTERY_ENABLE_PIN  23
#define BATTERY_R_TOP       100000.0f
#define BATTERY_R_BOTTOM    100000.0f
#define BATTERY_READ_INTERVAL_MS 10000

// --- Vibračný motorček ---
// Motorček je pripojený cez pôvodné dvojtranzistorové zapojenie priamo na ESP32.
// GPIO4 ovláda tranzistorový stupeň. LOG1 motor zapína.
#define MOTOR_PIN 4
#define MOTOR_ACTIVE_LEVEL HIGH
#define MOTOR_POLL_INTERVAL_MS 300

// --- Light sleep pri nečinnosti ---
#define INACTIVITY_TIMEOUT_MS         30000UL
#define LIGHT_SLEEP_CHECK_INTERVAL_MS 5000UL

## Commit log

2026-09-03 Initial firmware skeleton + wiring docs
2026-09-03 Fix: presunúť súbory z vnoreného priečinka do koreňa
    [config.h, main.cpp]
2026-09-04 Add files via upload
    popis ESP32
2026-09-04 Correct CON pin config and motor circuit to match empirically verified BUSY polarity (active HIGH)
    [config.h, main.cpp]
2026-09-07 Fix DY1703A begin() pin params; add simple UART test firmware
    [main.cpp]
2026-09-07 Add switched battery divider (BSS84+BS170) and light sleep on inactivity
2026-09-07 Fix WiFi AsyncWebServer startup order to prevent lwIP Invalid mbox crash
    [main.cpp]
2026-09-07 Fix WiFi settings watchdog reset: restart WiFi outside AsyncTCP callback
    [main.cpp]
2026-09-07 Fix settings save response and add WiFi password visibility toggle
    [main.cpp]
2026-09-07 Update vibration motor hardware configuration
    [config.h]
2026-09-07 Add per-track vibration control and direct active-HIGH motor output
    [main.cpp]
2026-09-07 Fix motor polling configuration
    [config.h]
2026-09-07 Pridaj diagnostiku UART komunikacie DY1703A
2026-09-07 Pridaj citatelny vypis UART komunikacie DY1703A
2026-09-11 Remap KEY1-KEY8 track GPIO assignments
2026-09-11 Pridaj ESP32 Dev Board pinout do docs
2026-09-12 Oprava uploadu loga – odpoveď POST handlera
2026-09-12 Add per-track LOOP playback setting
2026-09-12 Fix LOOP end detection and show LOOP on main page
    [main.cpp]
2026-09-12 Align track icons horizontally before track names
2026-09-12 Align LOOP and vibration icons in fixed columns
    [main.cpp]
2026-09-12 Fix maintenance button widths and box sizing
    [main.cpp]
2026-09-12 Use button for configuration backup action
2026-09-14 Add KiCad project
    [dy1703a.kicad_pcb, dy1703a.kicad_sch]
2026-09-14 Add DY1703A KiCad symbol and footprint
    [dy1703a.kicad_sch]
2026-09-16 Add LX-LCBST KiCad library
    [dy1703a.kicad_sch]
2026-09-16 Update KiCad project and symbols
    [dy1703a.kicad_sch]
2026-09-16 Update KiCad project and schematic
    [dy1703a.kicad_sch]
2026-09-16 doplnenie label
    [dy1703a.kicad_sch]
2026-09-16 Uprava popisky a generovanie pdf
    [dy1703a.kicad_sch]
2026-09-18 Add docs/kicad.md
2026-09-18 Update README with complete current project documentation
2026-09-18 Update wiring documentation to current GPIO mapping
2026-09-18 Align hardware documentation with current wiring
2026-10-01 Add track links, logos and card-based main UI
2026-10-01 Compact main playback controls and move device info to footer
2026-10-01 Refine playback status and compact volume battery row
2026-10-01 Add configurable track identifiers
2026-10-01 Refine volume battery layout and use fixed track IDs
    [main.cpp]
2026-10-01 Color logo status and simplify track numbering
2026-10-01 Prevent track logos from reloading on status refresh
    [main.cpp]
2026-10-01 Improve logo status and show device version in settings
2026-10-01 Update project documentation for current firmware
2026-10-01 Make device name larger than version in footers
2026-10-01 Add ESP32 pinout and audio samples
